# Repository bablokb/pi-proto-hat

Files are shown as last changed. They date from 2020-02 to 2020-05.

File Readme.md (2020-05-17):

Pi-Proto-Hat
============

This is a PCB design for a Pi-sized prototyping hat:

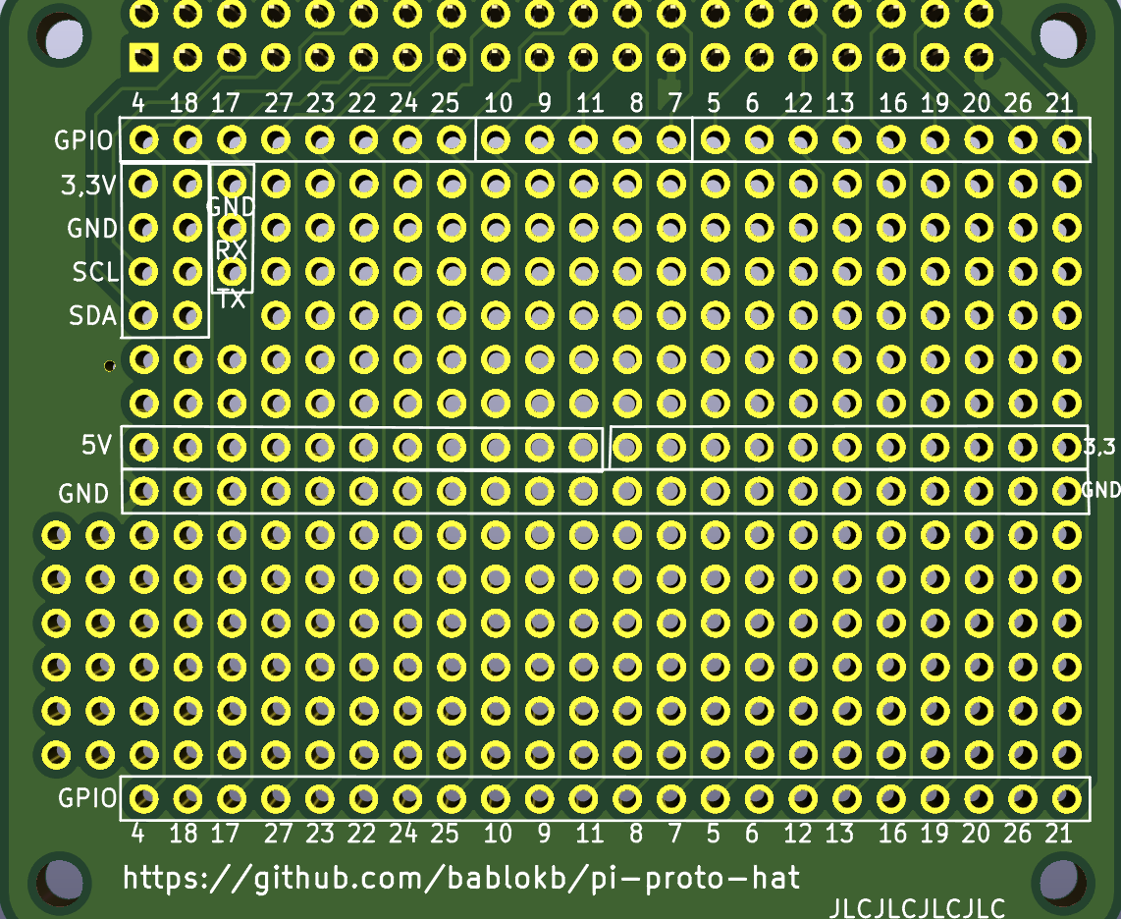
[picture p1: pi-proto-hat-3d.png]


The hat has a 40-pin connector for the Pi and exposes most of the GPIOs
on the top and bottom edge. On the left side you will find two connectors
for I2C and one for the UART-pins.

In the middle of the pcb there are two rows with power (5V and 3.3V) and
GND. The pins of the prototyping areas above and below the power-rails
are not connected.

In the directory `kicad/pi-proto-hat` you will find the complete
KiCAD project for the hat. The hat has been successfully produced
(by JLCpcb.com).

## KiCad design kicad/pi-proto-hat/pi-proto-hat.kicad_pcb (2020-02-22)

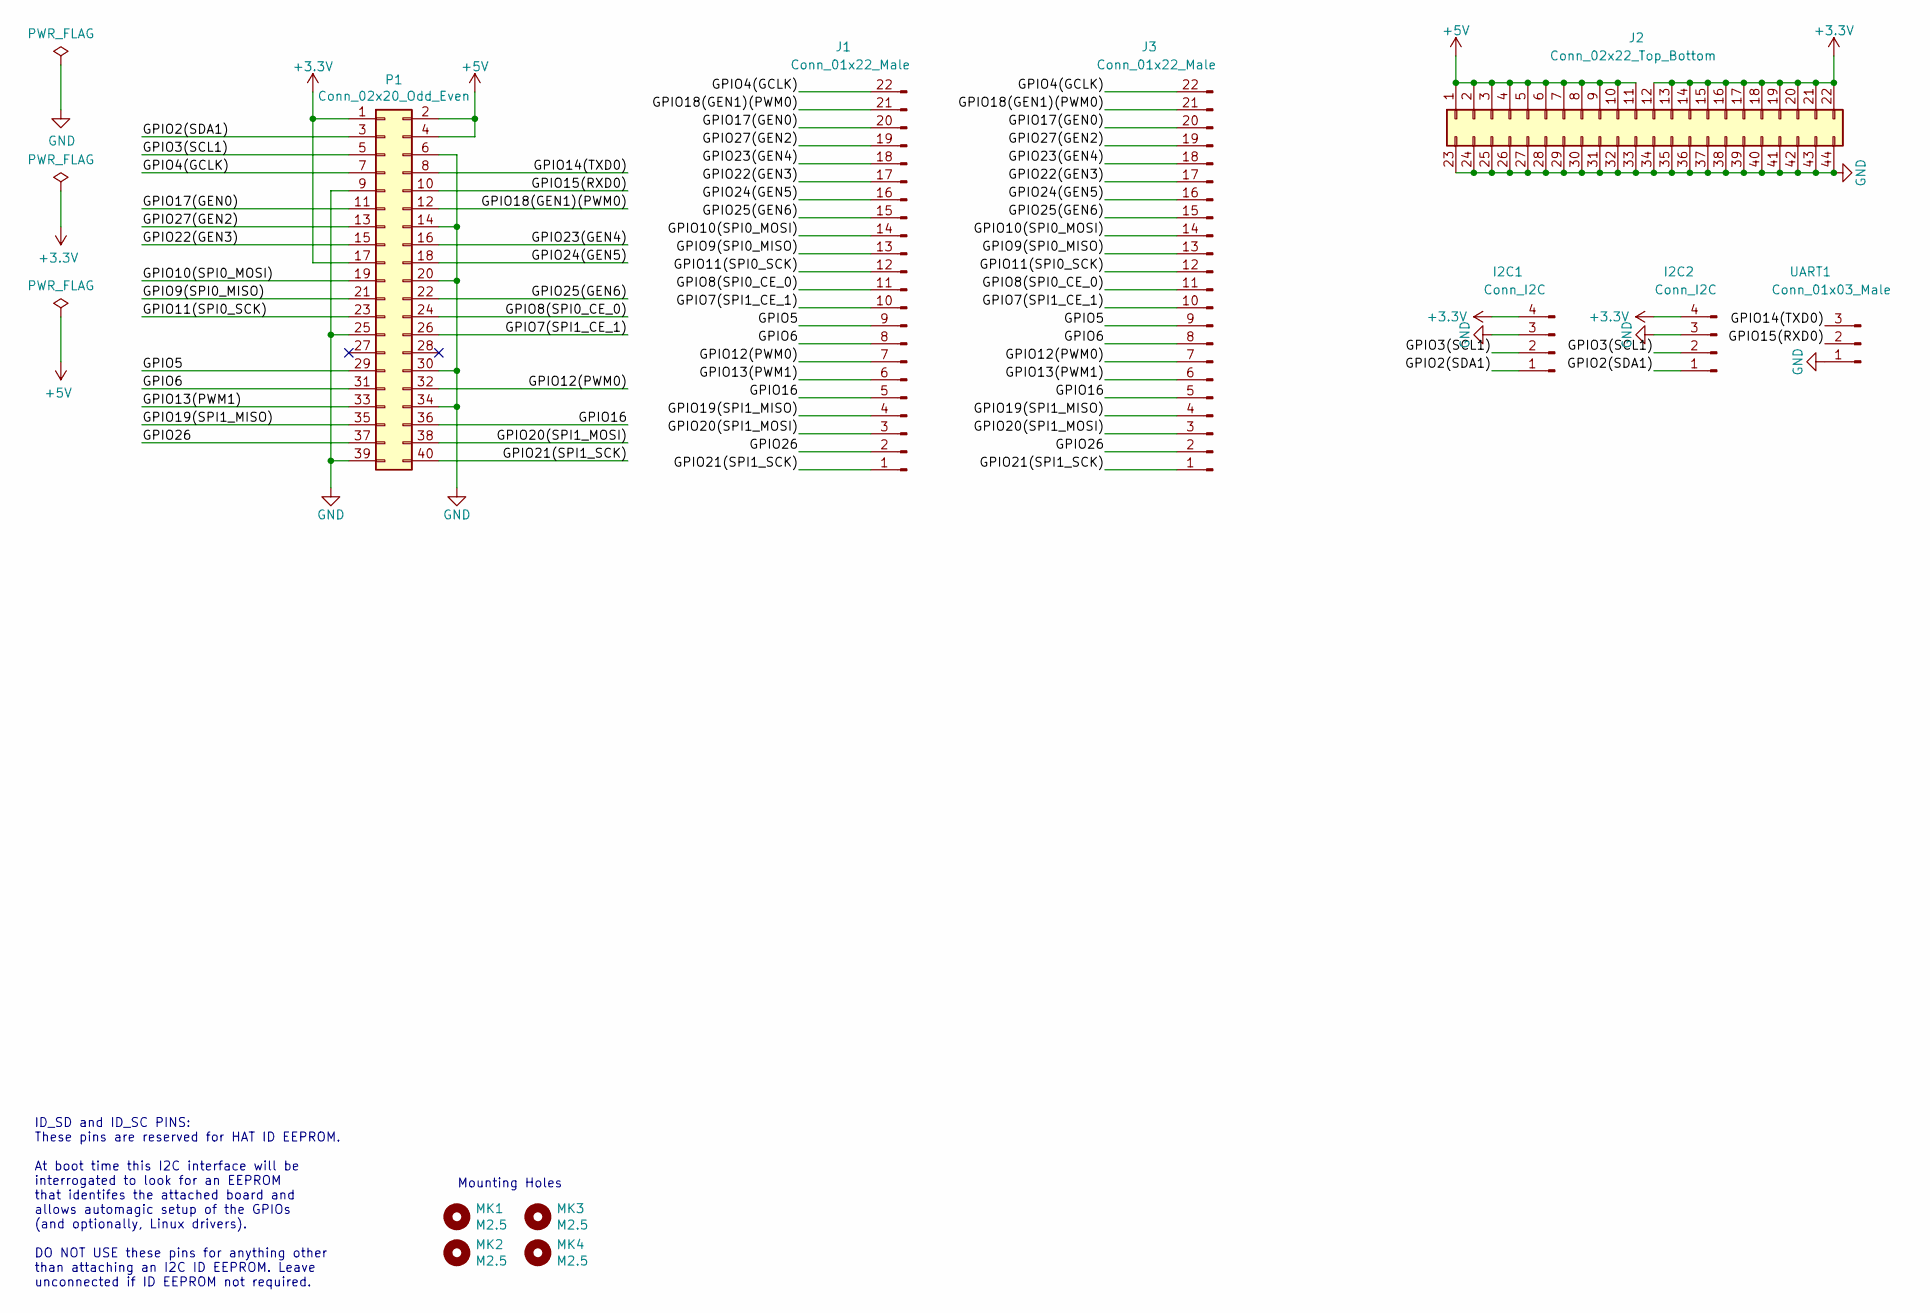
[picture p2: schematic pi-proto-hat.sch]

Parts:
I2C1, I2C2: Conn_I2C; Proto_Area_04x01
J1, J3: Conn_01x22_Male; Proto_Area_22x01
J2: Conn_02x22_Top_Bottom; Proto_Area_22x02
MK1, MK2, MK3, MK4: M2.5; MountingHole_2.7mm_M2.5
P1: Conn_02x20_Odd_Even; PinSocket_2x20_P2.54mm_Vertical
UART1: Conn_01x03_Male; Proto_Area_03x01

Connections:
+3V3: I2C1.4, I2C2.4, J2.12, J2.13, J2.14, J2.15, J2.16, J2.17, J2.18, J2.19, J2.20, J2.21, J2.22, P1.1, P1.17
+5V: J2.1, J2.2, J2.3, J2.4, J2.5, J2.6, J2.7, J2.8, J2.9, J2.10, J2.11, P1.2, P1.4
/GPIO2(SDA1): I2C1.1, I2C2.1, P1.3
/GPIO3(SCL1): I2C1.2, I2C2.2, P1.5
/GPIO4(GCLK): J1.22, J3.22, P1.7
/GPIO5: J1.9, J3.9, P1.29
/GPIO6: J1.8, J3.8, P1.31
/GPIO7(SPI1_CE_1): J1.10, J3.10, P1.26
/GPIO8(SPI0_CE_0): J1.11, J3.11, P1.24
/GPIO9(SPI0_MISO): J1.13, J3.13, P1.21
/GPIO10(SPI0_MOSI): J1.14, J3.14, P1.19
/GPIO11(SPI0_SCK): J1.12, J3.12, P1.23
/GPIO12(PWM0): J1.7, J3.7, P1.32
/GPIO13(PWM1): J1.6, J3.6, P1.33
/GPIO14(TXD0): P1.8, UART1.3
/GPIO15(RXD0): P1.10, UART1.2
/GPIO16: J1.5, J3.5, P1.36
/GPIO17(GEN0): J1.20, J3.20, P1.11
/GPIO18(GEN1)(PWM0): J1.21, J3.21, P1.12
/GPIO19(SPI1_MISO): J1.4, J3.4, P1.35
/GPIO20(SPI1_MOSI): J1.3, J3.3, P1.38
/GPIO21(SPI1_SCK): J1.1, J3.1, P1.40
/GPIO22(GEN3): J1.17, J3.17, P1.15
/GPIO23(GEN4): J1.18, J3.18, P1.16
/GPIO24(GEN5): J1.16, J3.16, P1.18
/GPIO25(GEN6): J1.15, J3.15, P1.22
/GPIO26: J1.2, J3.2, P1.37
/GPIO27(GEN2): J1.19, J3.19, P1.13
GND: I2C1.3, I2C2.3, J2.23, J2.24, J2.25, J2.26, J2.27, J2.28, J2.29, J2.30, J2.31, J2.32, J2.33, J2.34, J2.35, J2.36, J2.37, J2.38, J2.39, J2.40, J2.41, J2.42, J2.43, J2.44, P1.6, P1.9, P1.14, P1.20, P1.25, P1.30, P1.34, P1.39, UART1.1

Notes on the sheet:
ID_SD and ID_SC PINS: These pins are reserved for HAT ID EEPROM. At boot time this I2C interface will be interrogated to look for an EEPROM that identifes the attached board and allows automagic setup of the GPIOs (and optionally, Linux drivers). DO NOT USE these pins for anything other than attach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
Mounting Holes

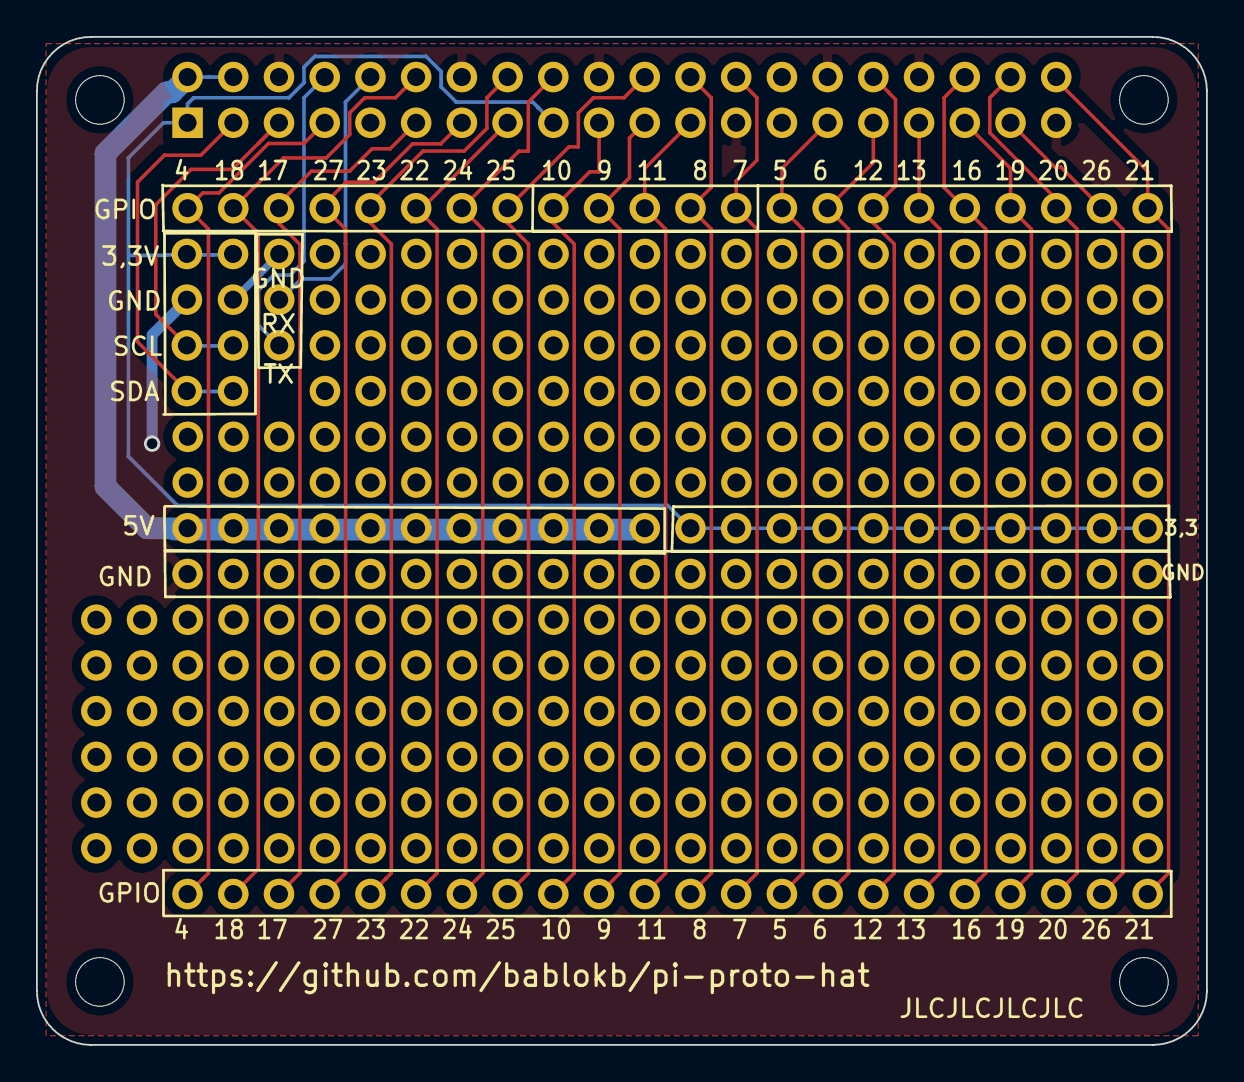
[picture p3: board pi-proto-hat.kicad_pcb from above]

Board: 2 copper layers, 65.0 x 56.0 mm, 11 parts (1 on the bottom side), 29 nets.

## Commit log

2020-01-30 R1: one GPIO connector, one I2C connector
    [pi-proto-hat.kicad_pcb, pi-proto-hat.sch]
2020-02-15 R2: 1xUART+GND, 2xI2C+VCC+GND
    [pi-proto-hat.kicad_pcb, pi-proto-hat.sch]
2020-02-15 R3: VCC+GND connector 22x02
    [pi-proto-hat.kicad_pcb, pi-proto-hat.sch]
2020-02-17 changed footprints, added two prototype-areas
    [pi-proto-hat.kicad_pcb, pi-proto-hat.sch]
2020-02-21 added routing for second GPIO connector
    [pi-proto-hat.kicad_pcb]
2020-02-21 changed/added prototyping areas to fill pcb
    [pi-proto-hat.kicad_pcb]
2020-02-22 removed unnecessary trace / configured gerber-plot
    [pi-proto-hat.kicad_pcb]
